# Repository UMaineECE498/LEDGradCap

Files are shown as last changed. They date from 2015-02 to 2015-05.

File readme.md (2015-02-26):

LEDGradCap
==========

The goal of this course is to create a device that can be given to each graduating ECE senior to wear at graduation.  The device will be battery powered and sized that it can be worn on the graduation cap, ideally clipped on rather than permanently affixed.  The device will have multiple LEDs and a three axis accelerometer.  The accelerometer can be used to measure movement which will translate to varying LED patterns.

More Information:
https://sites.google.com/a/maine.edu/ece498/

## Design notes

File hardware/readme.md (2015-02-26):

Hardware
==========

This directory contains the PCB and Schematic layout files.

Please note that the EDA suite is Kicad version 2014-jul-16

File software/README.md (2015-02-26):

Software
==========
This directory contains the software which will be used on the blinky board.

## Setting the atmega1284p to 8MhZ
    avrdude -p atmega1284p -P usb -c avrispmkII -U lfuse:w:0xc2:m -U hfuse:w:0x99:m -U efuse:w:0xff:m

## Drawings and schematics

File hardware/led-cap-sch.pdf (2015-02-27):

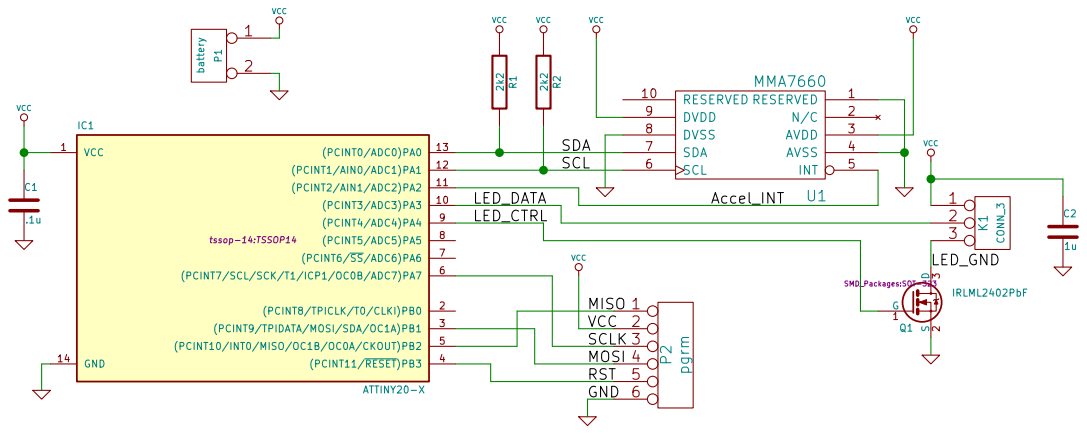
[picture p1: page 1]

LED_DATA
LED_CTRL

File: led-cap.sch Sheet: / UMaine

Id: 1/1 Title: ECE 498 CAP LED

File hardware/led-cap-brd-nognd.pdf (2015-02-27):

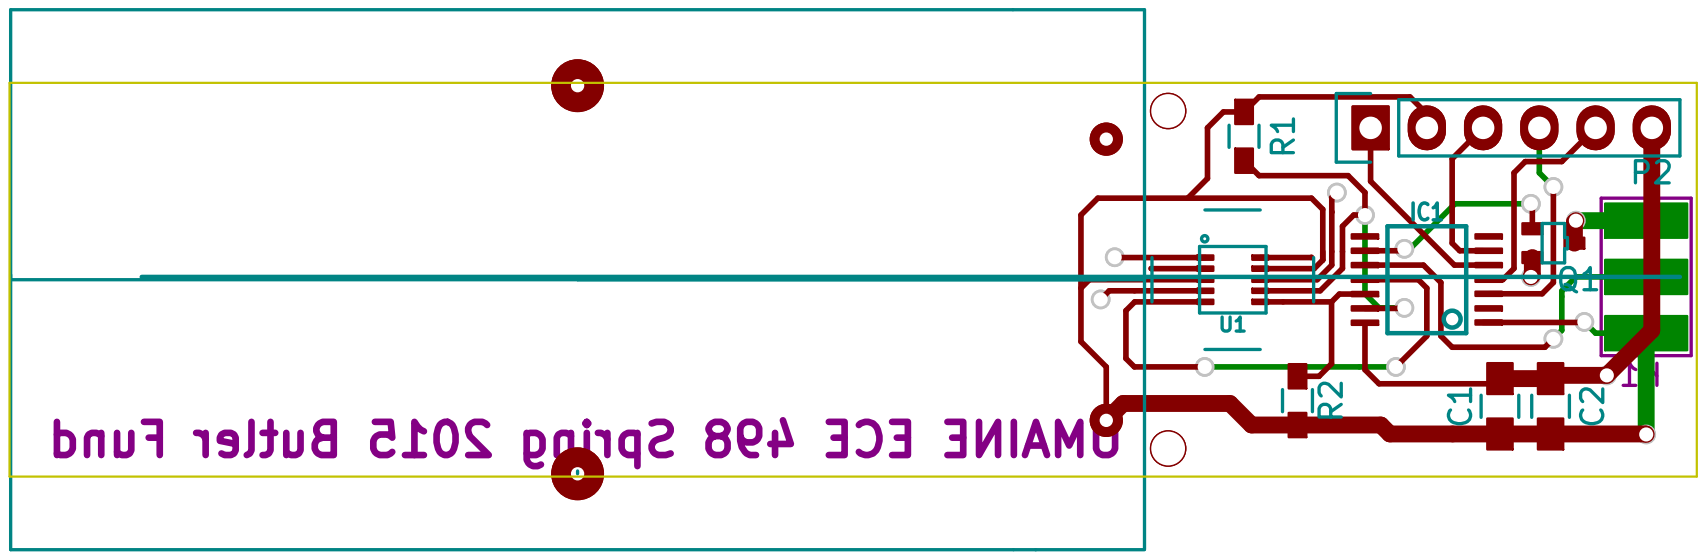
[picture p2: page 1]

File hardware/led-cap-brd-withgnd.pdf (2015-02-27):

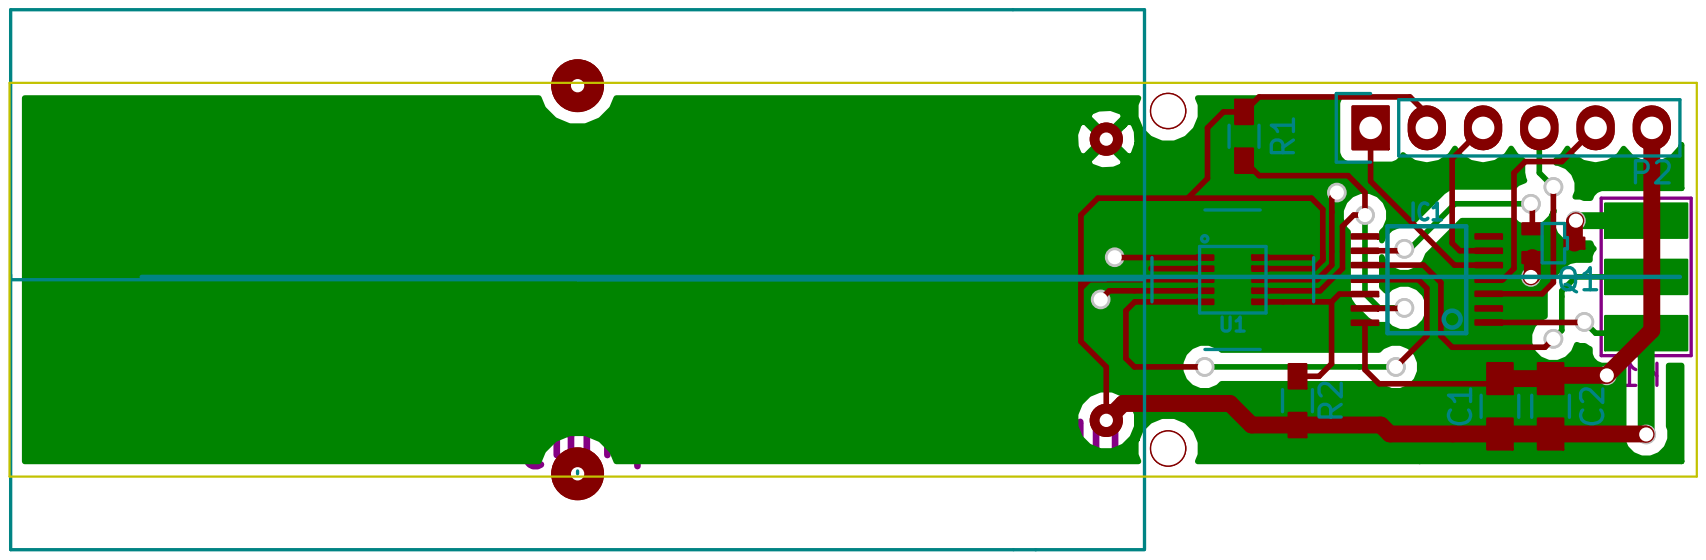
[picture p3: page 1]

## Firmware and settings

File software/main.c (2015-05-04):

#ifndef F_CPU
#define F_CPU 8000000UL
#endif
#include <avr/io.h>
#include <avr/interrupt.h>
#include <util/delay.h>
#include <string.h>
#include <avr/pgmspace.h>


#include "system.h"
#include "i2cmaster.h"
#include "led.h"
#include "accel.h"
#include "ledRoutines.h"



int grad_cap_mode(void);
void do_grad_cap(void);
void do_shaky_shaky(void);
uint8_t tilted_to_left(void);
// Initialize the system
void system_init(void);
void display_msg(void);


#define NUM_LOOPS 10		//number of loops
#define MAX_STEPS 5		//

uint8_t red[8] = { 0 };	// Red values
uint8_t green[8] = { 0 };	// Green values
uint8_t blue[8] = { 0 };	// Blue values

int main(void)
{
	system_init();		// System init
	send_leds(red, green, blue);	// turn lights off
	ORIENTATION_T orient;
	int8_t x = 0;
	int8_t y = 0;
	while (1) {
		orient = accel_get_orientation();
		if (orient == ORIENT_L) {
			LED_EN_PORT |= _BV(LED_EN_PIN);
			rgbfade();
		} else if (orient == ORIENT_R) {
			LED_EN_PORT |= _BV(LED_EN_PIN);
			bwfade();
			bwfade();
		}
		LED_EN_PORT &= ~_BV(LED_EN_PIN);
	}
	return 0;
}

// Initiailize the system
void system_init(void)
{
	// Remove System Clock Division
	CCP = 0xD8;
	CLKPSR = 0x00;

	// Enable LED Output Pins
	LED_DATA_PORT &= ~_BV(LED_DATA_PIN);	// Set output to zero first
	LED_DATA_DIR |= _BV(LED_DATA_PIN);	// LED TX line - need to be an output

	// Enable LED Output MOSFET
	LED_EN_PORT &= ~_BV(LED_EN_PIN);
	LED_EN_DIR |= _BV(LED_EN_PIN);
	LED_EN_PORT |= _BV(LED_EN_PIN);

	// Initialize bit-bang i2c and activate accelerometer
	i2c_init();

	i2c_start_wait((MMA7660_ADR << 1) + I2C_WRITE);
	i2c_write(0x07);	// Set Device in active Mode
	i2c_write(0x01);	// Write active mode bit
	i2c_stop();

	return;
}

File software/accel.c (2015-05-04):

#ifndef F_CPU
#define F_CPU 8000000UL
#endif
#include <avr/io.h>
#include <avr/interrupt.h>
#include <util/delay.h>

#include "i2cmaster.h"
#include "accel.h"

// Read from the specified register within the accelerometer
uint8_t accel_reg_read(uint8_t addr)
{
	uint8_t value;

	// Configure I2C Transaction

	// Left shift ADDR 1 bit.  I2c addresses are 7 bits, lsb sets mode
	i2c_start((MMA7660_ADR << 1) + I2C_WRITE);		// Start in write mode
	i2c_write(addr);								// Read from specified address

	i2c_rep_start((MMA7660_ADR << 1) + I2C_READ);	// Alert read mode
	value = i2c_readNak();							// Get the actual value
	i2c_stop();
	
	return value;
}

// For the given axis, calculate an average
int8_t axis_average(uint8_t axis)
{
	uint8_t i, v;	// Counter, temp variable for raw Accel value
	int16_t a=0;	// Average

	for (i=0;i<8;i++) {		// 8 time
		v=accel_reg_read(axis)&0x3F;	// Get X axis
		if (v&0x20) {		// Sign extend
			v=v|0xc0;
		}
		a+=v;				// Sum
	}
	a=a/8;					// Average
	return a;
}

ORIENTATION_T accel_get_orientation(void)
{
	int8_t threshold = 10;

	int8_t average = axis_average(ACCEL_X_AXIS);

	// Start with X Axis (Right/Left)
	if (average > threshold) {
		return accel_confirm_orientation(ORIENT_L, threshold);
	} 
	else if (average < -threshold) {
		return accel_confirm_orientation(ORIENT_R, threshold);
	}

	// Try Y axis (F/B)
	average = axis_average(ACCEL_Y_AXIS);	
	if (average > threshold){
		return accel_confirm_orientation(ORIENT_F, threshold);
	} else if (average < -threshold) {
		return accel_confirm_orientation(ORIENT_B, threshold);
	}

	return ORIENT_UK;		// Orientation not clear
}

ORIENTATION_T accel_confirm_orientation(ORIENTATION_T orientation, int8_t threshold)
{
	uint8_t i=0;
	int8_t x=0, y=0;

	for (i = 0; i < 8; i++)
	{
		_delay_ms(50);
		x = axis_average(ACCEL_X_AXIS);
		y = axis_average(ACCEL_Y_AXIS);

		if ((orientation == ORIENT_L) || (orientation == ORIENT_R)) {
			if ((-threshold < x) && (x < threshold)) {
				return ORIENT_UK;
			}
		} else if ((orientation == ORIENT_F) || (orientation == ORIENT_B)) {
			if ((-threshold < y) && (y < threshold)) {
				return ORIENT_UK;
			}
		}
	}

	return orientation;
}

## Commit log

2015-02-25 This is where Sheaff and I stopped
    [led-cap.kicad_pcb, led-cap.sch]
2015-02-25 Cleanup and PCB Layout
    [led-cap.kicad_pcb]
2015-02-26 Preliminary layout
    [led-cap.kicad_pcb, led-cap.sch]
2015-02-26 Just a bit of cleanup
    [led-cap.kicad_pcb]
2015-02-26 Using will's part of the accel
    [led-cap.kicad_pcb]
2015-02-26 Updating based on Sheaff & Segee recommendations
    [led-cap.kicad_pcb, led-cap.sch]
2015-02-27 Moving parts away from accelerometer
    [led-cap.kicad_pcb, led-cap.sch]
2015-02-27 Gerbers as uploaded to oshpark
    [led-cap.kicad_pcb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]
2015-03-21 Add led code
2015-03-21 Add led.h - header file for leds
2015-03-21 Added led code to makefile
2015-03-21 Setup main so LED lights - first blue
2015-03-23 Fixed programmer head from SPI to TPI
    [led-cap.sch]
2015-03-25 modifications necessary for attiny20 support, still not functioning completely correct
    [led.c, main.c]
2015-03-25 Fixing the mosfet
    [led-cap.kicad_pcb, led-cap.sch]
2015-03-25 fixing bit timings for attiny20
    [led.c, main.c]
2015-03-25 added i2c, demo code with accel feedback
2015-03-27 Fixed pcb and schematic for TPI and new LED strips
    [led-cap.kicad_pcb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]
2015-04-15 Contains files as submitted to PCBCart
    [led-cap.kicad_pcb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]
2015-05-01 Fix up in led.c so it will compile Add Sheaff's Makefile Removed comment out code from main
    [led.c, main.c]
2015-05-01 Fixed i2c read routine Add more of our functionality. - shakey part started - main routine does averaging and displays on the LEDs
    [accel.c, main.c, system.h]
2015-05-01 Tried to get the shakey thing to work - failed.
    [led.c, main.c]
2015-05-01 Broke out the accelerometer average
    [accel.c, main.c]
2015-05-01 Moved simpleFade() to ledRoutines.c,h
2015-05-01 commenting accelerometer
2015-05-02 added orientation detection and filtering functions
2015-05-04 This is the code that we are programming on the boards
